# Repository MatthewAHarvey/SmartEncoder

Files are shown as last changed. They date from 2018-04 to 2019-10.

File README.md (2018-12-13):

# SmartEncoder
Arduino friendly, serially addressable, ATTINY85 based rotary encoders. Reduce the pin count from 3 * n where n is the number of encoders (pins A, B and button C) to 2 total. Serial in, Serial out. Use Hardware Serial, AltSoftSerial or Software Serial

Handling lots of encoders at the same time can be a challenge. For example, in our use case, we had 15 encoders attached to one Arduino Mega. After all the connections to other peripherals, we ran out of pins. The encoders had to be polled since there are not enough interrupts. Our solution is to offload the handling of the encoders to dedicated ATTINY85 chips. These then talk asynchronous serial at 125000 baud in a ring with the master arduino. The arduino now only needs 2 pins: 1 serial tx and 1 serial rx. At the moment this is limited to one of the hardware serial ports but tests show it's possible with software serial implementations.

In order for this to work, the ATTINY85s' clock frequencies must be set more accurately than straight from the factory. 

### Installation instructions:

1. First, the ATTINYs must be frequency calibrated. We do this by burning the arduino bootloader on to an ATTINY and uploading the FreqCal sketch. We use the [ATTINYCore](https://github.com/SpenceKonde/ATTinyCore) which must be installed in the Arduino IDE. We output a square wave from pin 6 and observe it using an oscilloscope. An attached rotary encoder is then used to adjust this signal until it is as close to 1 MHz as possible. Pressing the encoder button saves the current OSCCAL register value to the EEPROM. 

Arduino IDE settings for ATTINY85:
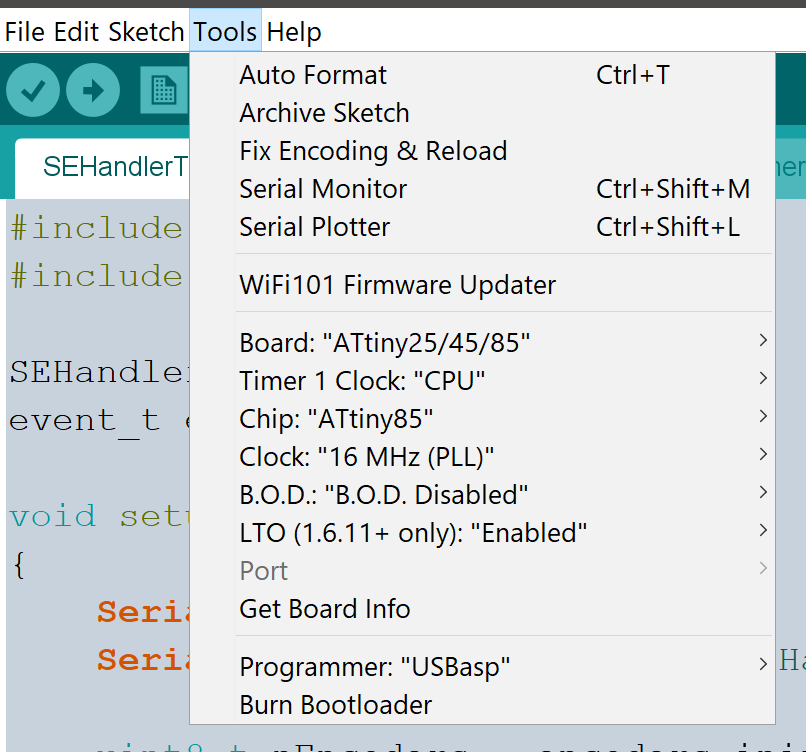
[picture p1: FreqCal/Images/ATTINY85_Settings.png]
ATTINY85 Settings


Schematic for the FreqCal rotary encoder programme:
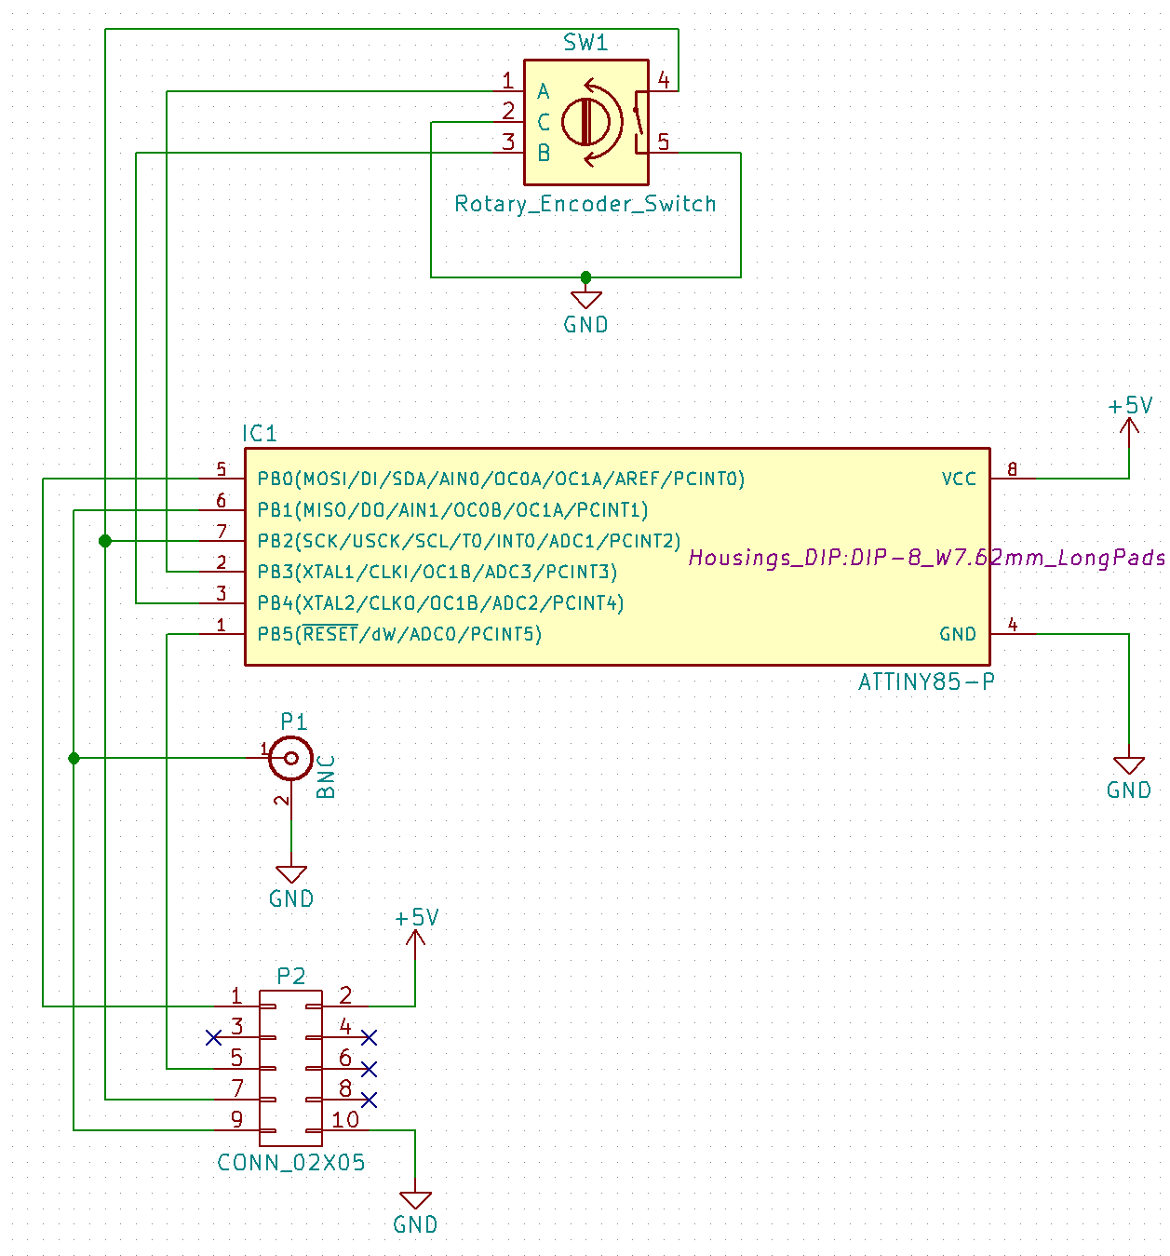
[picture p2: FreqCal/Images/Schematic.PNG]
Schematic


2. Now upload the ATTINY85RotEncCode sketch to each of the ATTINYs.

3. The example SEHandlerTest programme can be uploaded to the master arduino mega.

### To Do:
1. Add individual encoder direction swap command that can be called any time after init().
2. Add global encoder direction swap at creation time that tells all the individual encoders to swap direction at init time.

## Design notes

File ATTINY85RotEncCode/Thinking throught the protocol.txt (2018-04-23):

<C> is the command ascii letter
S for state (0 - off, 1 - encoder only, 2 - button only, 3 - both on)
D for debounce (0 to 9999ms)
C for double click max threshold (0 to 9999ms)
H for hold time min threshold (0 to 9999ms)
2 for encoder rate 2 max (0 to 9999ms)
3 for encoder rate 3 max (0 to 9999ms)

<STX><A1><A0><C><n3><n2><n1><n0><checksum><LF>

If I get <STX><0><2><H><1><0><0><0><checksum><LF> what happens?

<STX> starts serial message recording so msgIndex = 0
<0> goes in message[0], msgIndex = 1
<1> goes in message[1], msgIndex = 2
<H> goes in message[2], msgIndex = 3
<1> goes in message[3], msgIndex = 4
<0> goes in message[4], msgIndex = 5
<0> goes in message[5], msgIndex = 6
<0> goes in message[6], msgIndex = 7
<checksum> goes in message[7], msgIndex = 8
<LF> received so calculate checksum and parseMessage if it matches
    Checksum is message[msgIndex - 1]
    message to checksum is message[0] to message[6] 
    i.e. checksum(message, msgIndex)

What happens when I get a message?
1. If checksum matches
    2. If the message is set address, set my address, increment address, calculate new checksum and pass new message on
    3. Else If the message was global or for me, act on message and pass message along
    4. Else, pass message on
2. Else discard message

Build slave unit class on top of serial message class
Build master unit class on top of serial message class

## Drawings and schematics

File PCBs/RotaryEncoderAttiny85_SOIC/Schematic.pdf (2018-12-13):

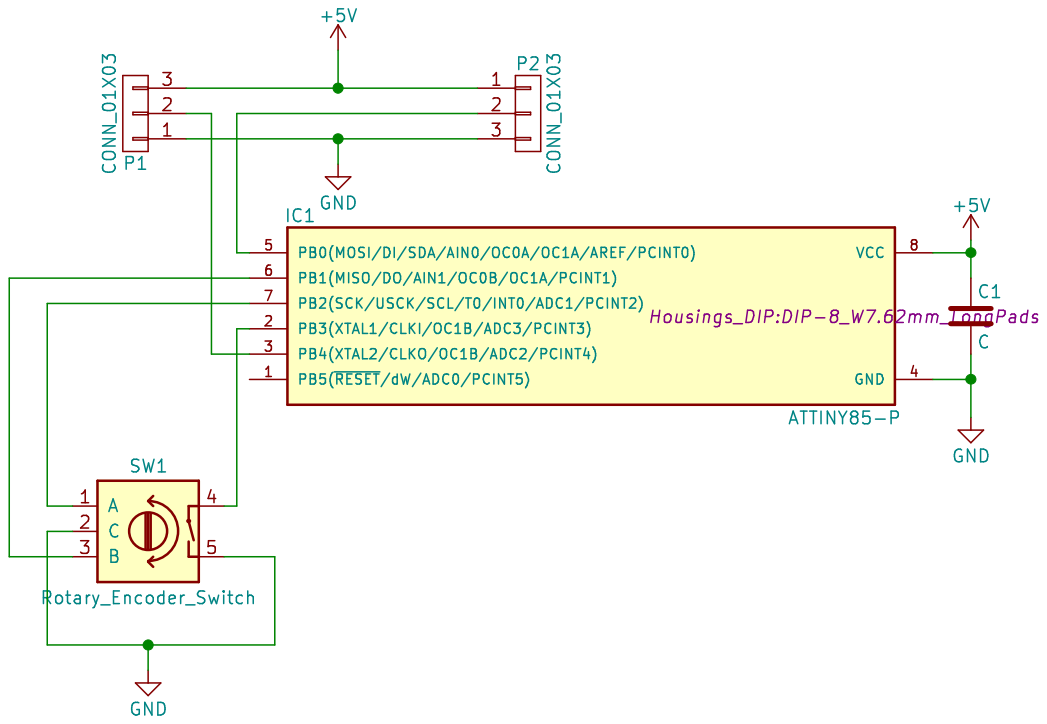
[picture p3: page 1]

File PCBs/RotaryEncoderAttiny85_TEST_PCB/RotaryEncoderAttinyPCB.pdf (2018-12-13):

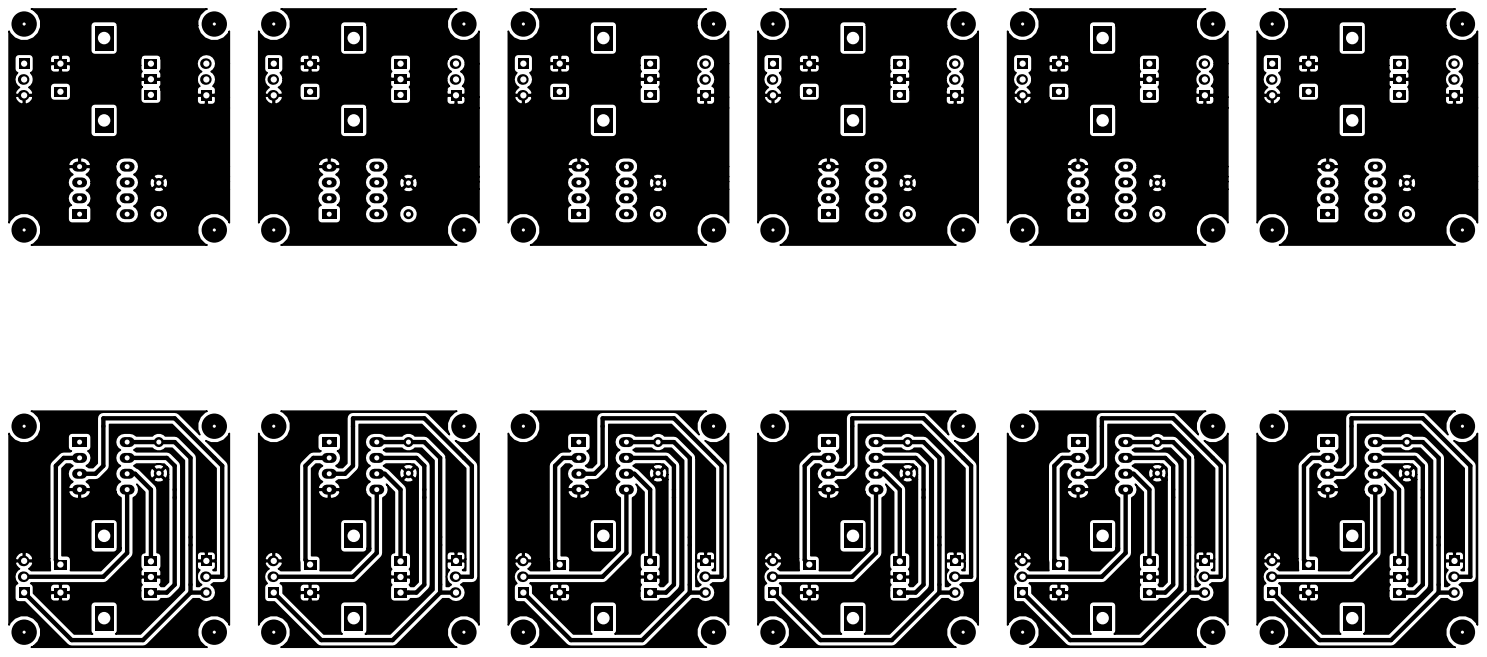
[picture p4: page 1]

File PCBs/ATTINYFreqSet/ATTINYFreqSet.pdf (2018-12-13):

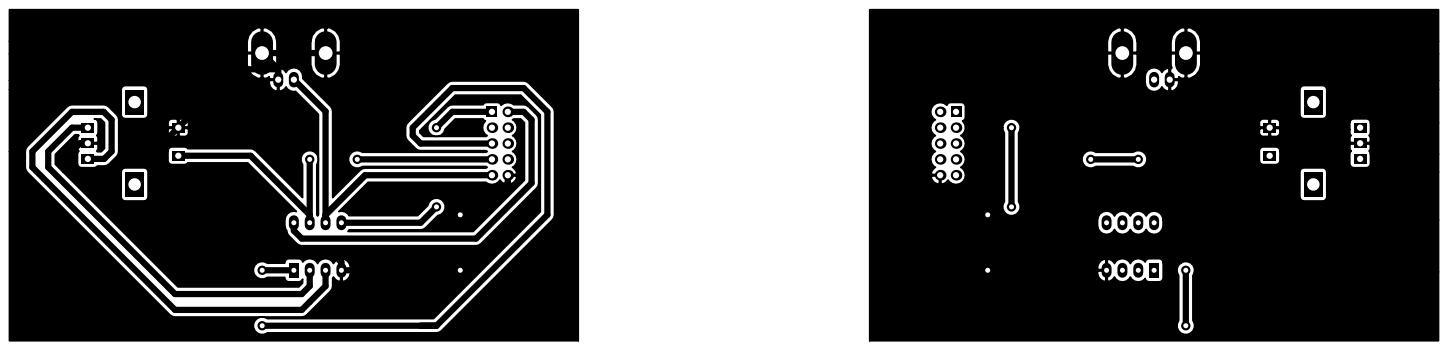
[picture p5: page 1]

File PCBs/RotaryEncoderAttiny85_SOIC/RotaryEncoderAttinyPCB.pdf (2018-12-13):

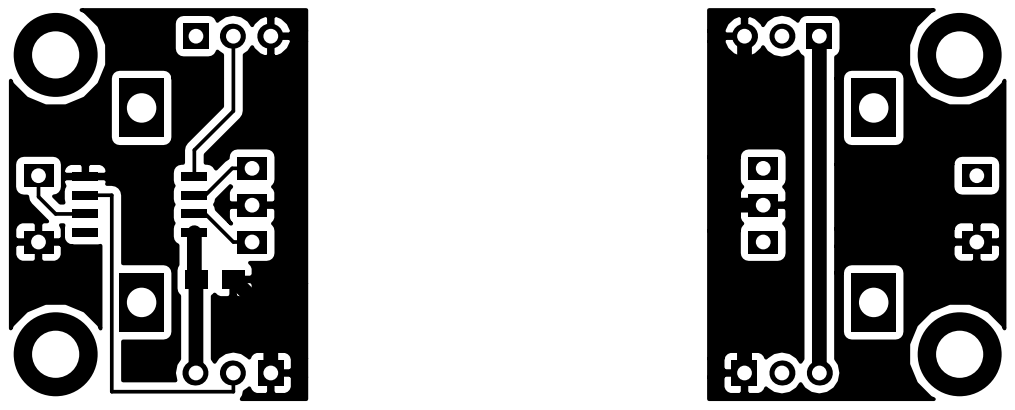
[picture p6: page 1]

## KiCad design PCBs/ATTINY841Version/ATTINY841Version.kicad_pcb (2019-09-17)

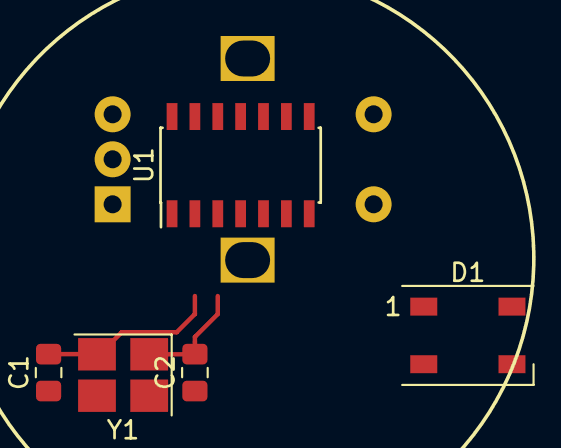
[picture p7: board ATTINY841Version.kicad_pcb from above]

Board: 2 copper layers, 6 parts (1 on the bottom side), 3 nets.

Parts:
C1, C2: C; C_0805_2012Metric_Pad1.15x1.40mm_HandSolder
D1: WS2812B; LED_WS2812B_PLCC4_5.0x5.0mm_P3.2mm
SW1: Rotary_Encoder_Switch; RotaryEncoder_Alps_EC12E-Switch_Vertical_H20mm
U1: ATtiny841-SSU; SOIC-14_3.9x8.7mm_P1.27mm
Y1: Crystal; Crystal_SMD_3225-4Pin_3.2x2.5mm_HandSoldering

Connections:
/XTAL1: C1.2, U1.2, Y1.2
/XTAL2: C2.2, U1.3, Y1.1
GND: C1.1, C2.1, SW1.C, SW1.S2, U1.14

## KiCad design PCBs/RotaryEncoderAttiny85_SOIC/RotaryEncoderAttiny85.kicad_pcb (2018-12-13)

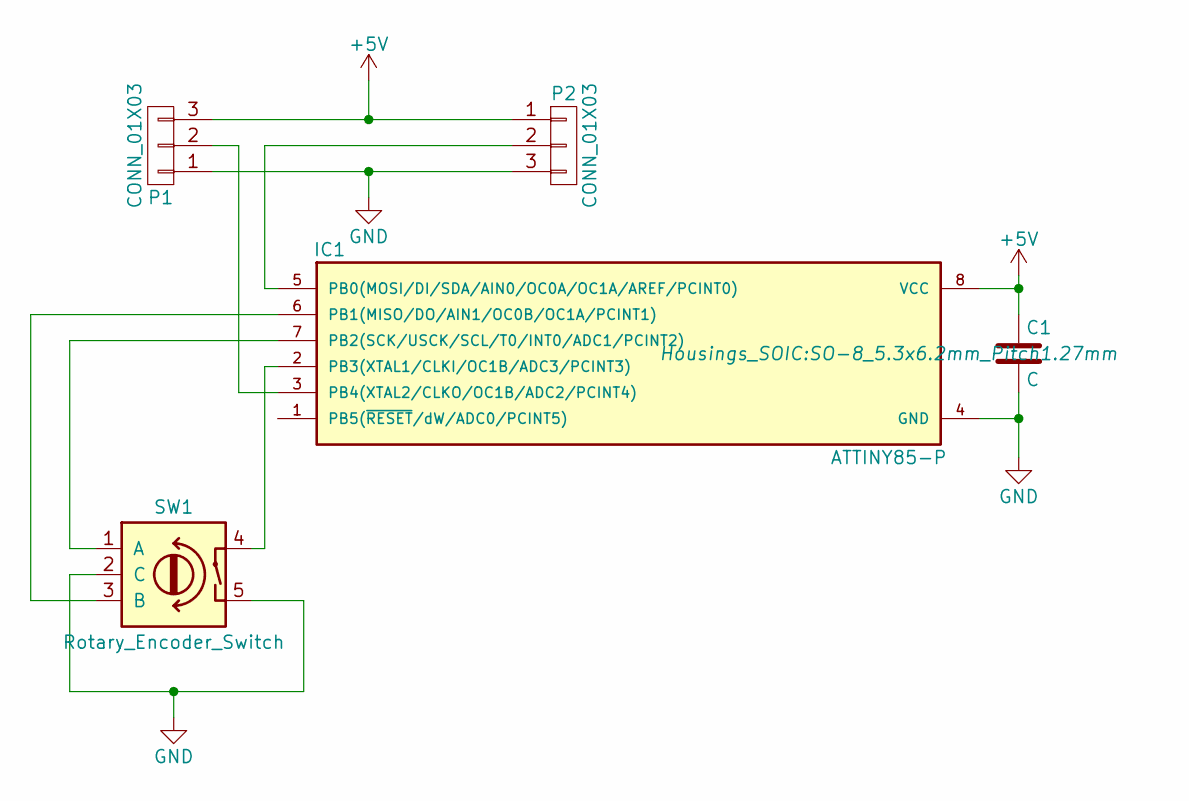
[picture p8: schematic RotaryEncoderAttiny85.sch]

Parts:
C1: C; C_0805_HandSoldering
IC1: ATTINY85-P; SO-8_5.3x6.2mm_Pitch1.27mm
P1, P2: CONN_01X03; Pin_Header_Straight_1x03_Pitch2.54mm
SW1: Rotary_Encoder_Switch; RotEnc

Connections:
+5V: C1.1, IC1.8 (VCC), P1.3, P2.1
GND: C1.2, IC1.4 (GND), P1.1, P2.3, SW1.2 (C), SW1.5
unnamed: IC1.2 (PB3(XTAL1/CLKI/OC1B/ADC3/PCINT3)), SW1.4
unnamed: IC1.3 (PB4(XTAL2/CLKO/OC1B/ADC2/PCINT4)), P1.2
unnamed: IC1.5 (PB0(MOSI/DI/SDA/AIN0/OC0A/OC1A/AREF/PCI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), P2.2
unnamed: IC1.6 (PB1(MISO/DO/AIN1/OC0B/OC1A/PCINT1)), SW1.3 (B)
unnamed: IC1.7 (PB2(SCK/USCK/SCL/T0/INT0/ADC1/PCINT2)), SW1.1 (A)

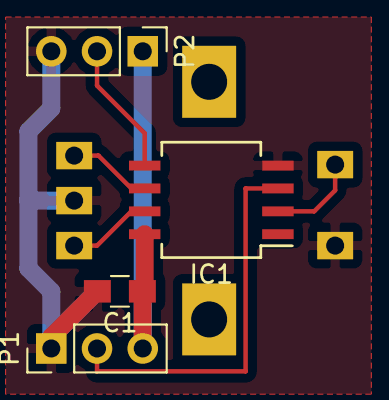
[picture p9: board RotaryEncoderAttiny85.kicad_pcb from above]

Board: 2 copper layers, 5 parts (1 on the bottom side), 7 nets.

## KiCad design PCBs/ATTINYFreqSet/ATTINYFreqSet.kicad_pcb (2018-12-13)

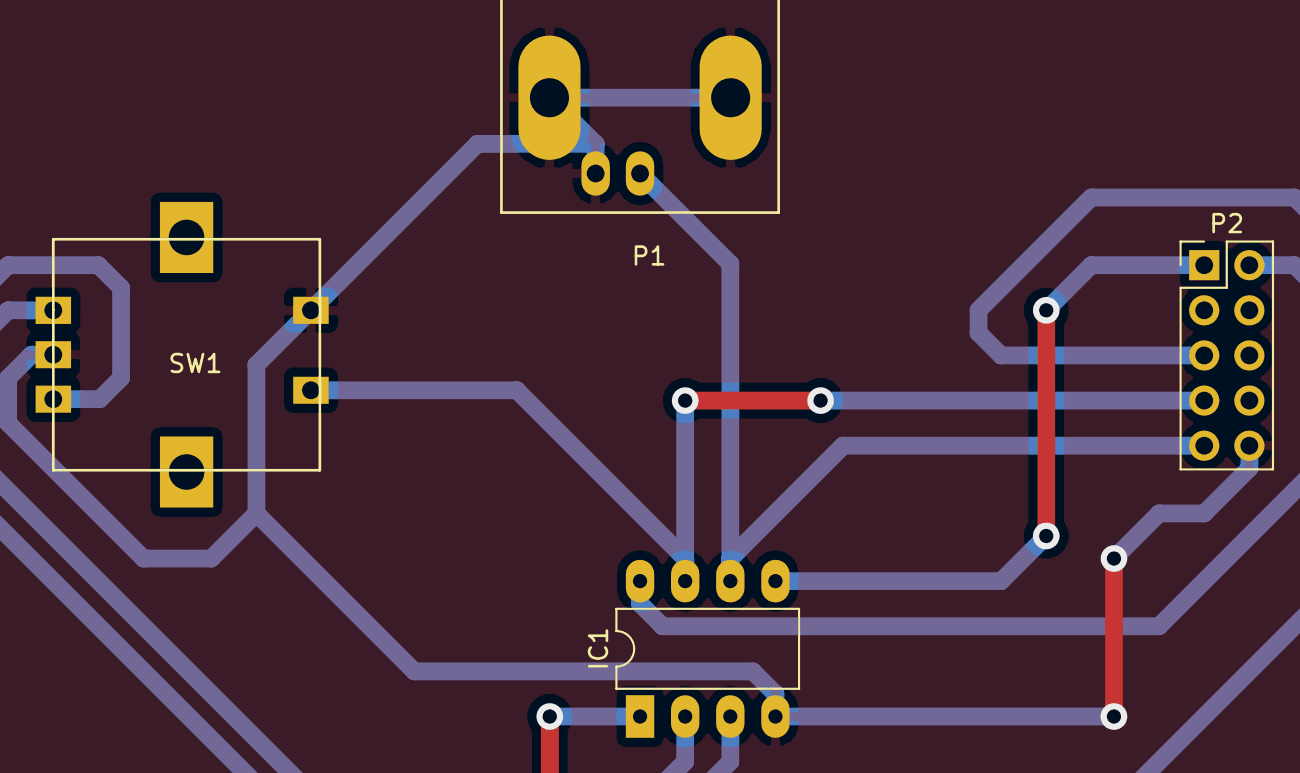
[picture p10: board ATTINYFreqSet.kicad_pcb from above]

Board: 2 copper layers, 4 parts (0 on the bottom side), 8 nets.

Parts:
IC1: ATTINY85-P; DIP-8_W7.62mm_LongPads
P1: BNC; BNC_Socket_TYCO-AMP_LargePads
P2: CONN_02X05; Pin_Header_Straight_2x05_Pitch2.54mm
SW1: Rotary_Encoder_Switch; RotEnc

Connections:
+5V: IC1.8, P2.2
GND: IC1.4, P1.2, P2.10, SW1.2, SW1.5
unnamed: IC1.1, P2.5
unnamed: IC1.2, SW1.1
unnamed: IC1.3, SW1.3
unnamed: IC1.5, P2.1
unnamed: IC1.6, P1.1, P2.9
unnamed: IC1.7, P2.7, SW1.4

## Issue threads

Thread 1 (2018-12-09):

SmartEncoder Pinout

rolfmeurer, 2018-12-09:
I'm a bit confused about diferent encoder pinout in  FreqCal.ino and ATTINY85RotEncCode.ino

is there a diferent hardware pinout for FreqCal and for the Main program?

I am up to design an encoder  PCB with LEDs, but it's not clear if the FreqCal schematic works as it is for the main program too.
Neither clear is the need of the Pushbutton wiring to the CONN_ß2X05  P2 connector. Is this only for the FreqCalc or for further usage too?

FreqCal.ino:
const int encPinA = 3; //pin 2
const int encPinB = 4; //pin 3
const int encPinC = 2; //pin 7

ATTINY85RotEncCode.ino:
const int encPinA = 2; //pin 7, PCINT2
const int encPinB = 1; //pin 6, PCINT1
const int encPinC = 3; //pin 2, PCINT3

MatthewAHarvey, 2018-12-10:
Hi Rolf,

I use the ATTINY85 without a crystal and the serial communications relies on all the ATTINY's clocks to be synchronised to within 1-2% or so. You can tune AVR chips by tweaking OSCCAL variable which I had done for previous projects. As such, I already had a board that I use to tune the frequencies. When the FreqCal.ino program is flashed to the ATTINY, I tune OSCCAL by watching a frequency generated
 on pin PB1. The rotary encoder changes the current OSCCAL and the encoder's button is pushed to set this value in the EEPROM. I read this value in all my subsequent ino scripts and set the frequency to that tuned OSCCAL in my void setup routine.

I made a little board that only has a BNC out to measure the frequency of a generated signal, a rotary encoder and a CONN_B2X05 connector which is used to plug in a USBASP programmer to flash the ATTINY chip with. Once I've set the OSCCAL freq, I reflash the chip with the smartencoder firmware and remove the chip from the board. I do this for all the chips in my project by first tuning the frequency on all the chips to be used, then flashing them all with the smartencoder firmware. Takes around a minute per chip. The programmer shares some pins with the rotary encoder on the board via the CONN_B2X05 connector. As long as I don't touch the encoder while the chip is being flashed, there are no problems doing this.

I have separate board layout for the smart encoder part that uses the pins set up in the ATTINY85RotEncCode.ino sketch. I should have uploaded this schematic and board layout too.

Does the above make sense?

I will remove the need for tuning the onboard oscillator frequency in future by using a chip with more pins available and hook up a crystal to provide a much more accurate clock.

Do you mind me asking what you have in mind with this code? I uploaded it here in this poorly documented state since I was explaining how to use it to colleagues and friends in person. I will tidy up the documentation and upload clearer code in the near future but probably not this week. If you would like a basic board layout for the smart encoder, I'll try to upload my Kicad projects here within a day or two.

Regards,
Matthew

rolfmeurer, 2018-12-11:
Hi Matthew,

Thank you for the kindly answer.

I have an encoder layout with an LED ring works perfectly, but needs an
arduino MINI PRO  each.

I hope I can merge your ATTiny smart encoder with my LED RING (using a
74HC595 4x4 LED matrix) to get it all on a tiny PCB  just as an universal
Encoder module.

It shouldn't become a little tiny module just 30x30mm as it is now and on
the buttom lay is still enough place to ge an ATTiny placed your FreqCalc
schematic fits onto the PCB

 Can you please send me a link to the schematic of the main smart encoder?

I'm fine with ATTINY a bigger chip would exceed the PCB layeout size

I'm working for KRAFTWERK and I'm always looking for new devices to give our
equipment more haptic.

Rregards,

Rolf

  _____

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

MatthewAHarvey, 2018-12-13:
Hi Rolf,

Your use case is exactly what I had in mind for this project so this is exciting. I am also interested in feedback and physical controls and have been disappointed with modern tactileless touchscreens appearing everywhere. Also, often modern controls just feel slow and clunky. The volume control knob in my car is very slow and the aircon temperature knob's encoder would miss events and not respond if not turned extremely slowly. That was very annoying in the summer heat when getting in to the car. I have thought about making a synthesizer but I have zero musical ability. KRAFTWERK is great too by the way.

I have just uploaded some Kicad projects to the PCBs subfolder for you. The ATTINYFreqSet board is my crude way to tune the oscillator frequencies and flash the chips before installing them in their final boards. The RotaryEncoderAttiny85_TEST_PCB one is my original test board where I daisy-chained 5 smart encoders together. Both of these boards use DIP packaged ATTINYs for ease of use while I developed the principle. The final board, RotaryEncoderAttiny85_SOIC, should work and on this one the ATTINY is a SOIC package and would fit beneath the encoder. I don't have a programmer board, or better still a header for programming the chip in place on this. The SOIC chips have been sat on my shelf for six months waiting for me...

At the moment, I used three for a LED strip controller toy that I built for my son and about 60 or so in a physics research lab where we build our own computer controlled power supplies etc. There are 3 power supplies with about 20 smart encoders each. This frees up a controlling arduino to respond to the power requirements and control requests whilst continuously updating an LCD panel at a much faster rate than an older design which had to poll many encoders. I can tell you that these power supplies have been in daily use for 6 months or so without a single problem so this serial daisy chain method seems to work very well. They don't look pretty because we didn't finish them before putting them in to use. One day...

Power supply control panels:
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

My son's toy during development (it's still not finished):
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

Very early test board and the one I used in my son's toy:
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

I have been discussing expanding on this smart encoder idea with some friends including status LEDs as you are doing. When a microcontroller is now so cheap, why not use many to make the design process easier and offload processing from the main controller?

The current firmware allows for the following events:
Clockwise rate 1
Clockwise rate 2
Clockwise rate 3
Anticlockwise rate 1
Anticlockwise rate 2
Anticlockwise rate 3
Button down
Button up
Button hold
Button doubleclick

The rates can be tuned to feel very good. For example, it's very easy to set our power supplies with milliVolt accuracy in 0.001V steps when rotating an encoder slowly, Move it in 0.1 Volt steps at a normal/natural rotation speed and very rapidly in say 10V steps for rapidly changing the voltage by a few hundred volts. It feels intuitive and makes our instruments very easy to tune. More than three rates could be used but I haven't coded them yet as we haven't felt the need. It would provide even more nuanced control though.

With regards to your LED ring, I don't think there are enough spare pins on an ATTINY85 to do this? As you can hopefully see from picture three though, there would be plenty of room to fit an MCU with more pins in SOIC package or possibly even DIP if it was mounted on the opposite side of the board and still fit your 74HC595 plus LEDs. For reference, the knobs on our power supplies are 36 mm apart and they are 40mm apart on my original test board. That board includes space for in and out connectors though so easily could be shrunk down.

I'll be updating the code to make it more readable soon. Especially the serial handling code on the ATTINY85RotEncCode.ino sketch.

Regards,
Matthew

rolfmeurer, 2018-12-13:
Hi Matthew,

Great project you Power Supply.

Nice and good readable Analyzer display design.

About the pins, the LED Ring is driven by a 74HC595.

So the Encoder and the LED ring could communicate serially  with the tiny

I think it  could work anyhow   by puzzle & pray

And one PCB should not exceed 30mm x 30mm to align them know by know
horizontally as well as vertically.

On my PCB top layer is still enough space to add a Tiny85 SOT and perhaps 4
resistors or capacitors .

Chips with more pin's I'm not sure it would match on the PCB, but if so,
then it's a great benefit.

Here comes a snap from a 9x9 encoder & LED proto PCB

Regards Rolf

  _____

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

MatthewAHarvey, 2018-12-13:
Hi Rolf,

Thanks for the comments about the analyser power supply, however I can not take credit for that design. My friend and colleague Ahmad designed and built those power supplies including all the display stuff. I just provided the smart encoder bit with a lot of input and help from Ahmad. He is visible in the background photo on his [website](https://ahmadsakaamini.com/about/), which was taken in our research lab.

Can you try attaching your picture again please? Nothing is showing. Perhaps I can help you with your design? Also, have you seen this [palettegear](https://palettegear.com/) stuff? Very slick and very expensive but they seem to have thought along the same/similar lines to us.

Matthew

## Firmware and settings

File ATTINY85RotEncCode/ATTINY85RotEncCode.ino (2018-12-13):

// ATTINY85 code for rotary encoder
// 16 MHz PLL works well.
// Enable BOD to prevent frozen states of the ATTINY in the case of a power dip.
// Must flash FreqCal and adjust oscillator with oscilloscope or frequency counter to ensure serial works properly
// Tested with 3 encoders and a hardware serial port on a mega, each message takes 5us and I can generate over 400 events per second when turning an encoder as fast as I can. It goes even faster when I turn two encoders. There will be misses but this is still a responsive system.

#include "Encoder.h"
#include <SoftwareSerial.h>
#include <EEPROM.h>

const long baudrate = 125000;
const int tx = 0; // software serial transmit. pin 5
const int rx = 4; // software serial receive. pin 3
SoftwareSerial SSerial(rx, tx);

// define pins. A=2,B=1 for Ahmad's power supplies
const int encPinA = 2; //pin 6, PCINT1
const int encPinB = 1; //pin 7, PCINT2
const int encPinC = 3; //pin 2, PCINT3
bool reverseDirection = false; // By default, keep direction as wired in reference design
Encoder enc(encPinA, encPinB, encPinC);

// start and stop chars
const char STX = 0x02; // start transmission ascii code
const char LF = 0x0A; // line feed ascii code

uint8_t msgIndex;
static const uint8_t LEN = 9;
char message[LEN]; // max length of a message. NOT terminated by \0   

//int address = -1;
char address[] = "00";
uint8_t addressInt = 0;

//typedef enum {WAITING_FOR_ADDRESS, RUNNING} runModes;
//typedef enum {WAITING_FOR_START, COLLECTING_MESSAGE} serialModes;
enum runModes{WAITING_FOR_ADDRESS, RUNNING};
enum serialModes{WAITING_FOR_START, COLLECTING_MESSAGE};

runModes state;
serialModes serialState;

// Protocol:
// No rotary encoder events will be registered until the unit has received an address.
// The address takes the form of two hex chars to allow the address of a unit to be set between 0 and 254. All units respond to 255 since this is the global update address.
// The master must send <STX><Address1><Address0><checksum><LF> to set the first unit's address. This unit then increments this address and passes it on. Do not overflow 254!!!
// Set the debounce with <STX><A1><A0><D><n><checksum><LF> where n is the debounce time in milliseconds.
// Enable or disable the encoder with <STX><A1><A0><E><n><checksum><LF> where n is 1 or 0.

// Except for address messages, all messages are echoed.
// Rotary encoder events are broadcast <STX><A1><A0><x><checksum><LF> where A1, A0 give the encoder address 
// and x is 0 for clockwise step at rate 1
//          1 for clockwise step at rate 2
//          2 for clockwise step at rate 3
//          3 for anti-clockwise step at rate 1
//          4 for anti-clockwise step at rate 2
//          5 for anti-clockwise step at rate 3
//          6 for button up
//          7 for button down
//          8 for button doubleclick
//          9 for button hold


void setup()
{
    updateOscFreq();

    enc.init();
    SSerial.begin(baudrate);
    //state = RUNNING;
    state = WAITING_FOR_ADDRESS;
    serialState = WAITING_FOR_START;    
}

void loop()
{
    checkSerial();
    checkEncoder();
}

void checkEncoder()
{
    if(state == RUNNING)
    {
        if(!reverseDirection)
        {
            switch(enc.poll())
            {
                case NO_CHANGE:
                    break;
                case CW_RATE1: 
                    sendState(0);
                    break;
                case CW_RATE2:
                    sendState(1);
                    break;
                case CW_RATE3: 
                    sendState(2);
                    break;
                case ACW_RATE1: 
                    sendState(3);
                    break;
                case ACW_RATE2: 
                    sendState(4);
                    break;
                case ACW_RATE3: 
                    sendState(5);
                    break;
                case BUTTON_UP: 
                    sendState(6);
                    break;
                case BUTTON_DOWN: 
                    sendState(7);
                    break;
                case BUTTON_DOUBLECLICK: 
                    sendState(8);
                    break;
                case BUTTON_HOLD:
                    sendState(9);
                    break;
            }
        }
        else
        {
            switch(enc.poll())
            {
                case NO_CHANGE:
                    break;
                case CW_RATE1: 
                    sendState(3);
                    break;
                case CW_RATE2:
                    sendState(4);
                    break;
                case CW_RATE3: 
                    sendState(5);
                    break;
                case ACW_RATE1: 
                    sendState(0);
                    break;
                case ACW_RATE2: 
                    sendState(1);
                    break;
                case ACW_RATE3: 
                    sendState(2);
                    break;
                case BUTTON_UP: 
                    sendState(6);
                    break;
                case BUTTON_DOWN: 
                    sendState(7);
                    break;
                case BUTTON_DOUBLECLICK: 
                    sendState(8);
                    break;
                case BUTTON_HOLD:
                    sendState(9);
                    break;
            }
        }
    }
}

void updateOscFreq()
{
    if(EEPROM.read(0) == 'C' && EEPROM.read(1) == 'A' && EEPROM.read(2) == 'L')
    {
        OSCCAL = EEPROM.read(3);
    }
}

void sendState(int i)
{
    if(0 <= i && i < 10)
    {
        message[0] = address[0];
        message[1] = address[1];
        message[2] = i + '0';
        message[3] = calcChecksum(message, 3);

        SSerial.write(STX);
        for(int i = 0; i < 4; i++)
        {
            SSerial.write(message[i]);
        }
        SSerial.write(LF);
    }
}

void checkSerial()
{
    while(SSerial.available())
    {
        char in = SSerial.read();
        
        switch(serialState)
        {
            case WAITING_FOR_START:
                if(in == STX)
                {
                    serialState = COLLECTING_MESSAGE;
                    msgIndex = 0;
                }
                break;
            case COLLECTING_MESSAGE:
                if(in == LF)
                {
                    serialState = WAITING_FOR_START;
                    // Calculate checksum and make sure it matches. If it does, parse the message
                    uint8_t msgLen = msgIndex - 1;
                    if(message[msgLen] == calcChecksum(message, msgLen))
                    {
                        // Parse message
                        //SSerial.write(STX);
                        //SSerial.print("Received good message.");
                        //SSerial.write(LF);
                        parseMessage();
                    }
                }
                else if(in == STX)
                {
                    //something must have glitched so reset msgIndex to start again
                    msgIndex = 0;
                }
                else if(msgIndex < LEN)
                {
                    message[msgIndex] = in;
                    msgIndex++;
                }
                else
                {
                    //message would now be too long so go back to waiting for a new reading
                    serialState = WAITING_FOR_START;
                }
                break;
        }
    }
}

void parseMessage()
{
    char type = message[2];
    unsigned int value = 0;
    switch(msgIndex)
    {
        case 3: // set address and set mode to RUNNING
            if(validAddress())
            {
                address[0] = message[0];
                address[1] = message[1];
                state = RUNNING;
                // Now we need to increment the address and pass it on. To do this, convert the address to an int, increment it, convert it back to hex array then send this.
                sendNextSetAddress();
            }
            break;
        case 4: // get value of something
            //char type = message[2];
            if(addressMatch())
            {
                message[0] = address[0]; // update these in case the message was to all units.
                message[1] = address[1];
                switch(type)
                {
                    case '2': // rate 2 max (ms)
                        value = enc.getRate2Max();
                        break;
                    case '3': // rate 3 max (ms)
                        value = enc.getRate3Max();
                        break;
                    case 'C': // double click max (ms)
                        value = enc.getDoubleClickMax();
                        break;
                    case 'D': // button debounce time (ms)
                        value = enc.getDebounceTime();
                        break;
                    case 'H': // hold button min (ms)
                        value = enc.getButtonHoldTime();
                        break;
                    case 'R':
                        value = (uint16_t) reverseDirection;
                        break;
                    case 'S': // set the state of the encoder
                        // 0 button and encoder disabled
                        // 1 button enabled, encoder disabled
                        // 2 button diasbled, encoder enabled
                        // 3 both enabled
                        value = enc.getState();
                        break;
                }
                sendValue(value);
            }
            else
            {
                echoSerial();
            }
            break;
        case 5: // If the length is between 5 and 8, a value is being set between 0 and 9999 (usually ms).
        case 6:
        case 7:
        case 8:
            // Echo the message so that it reaches the master. This way the master can check setting messages were received, and any encoder updates get passed along.
            echoSerial();
            // Now check whether I need to set something
            if(addressMatch() || globalMatch())
            {
                // The message is for us so parse it
                //char type = message[2];
                int value = messageToInt(3);
                switch(type)
                {
                    case '2': // rate 2 max (ms)
                        enc.setRate2Max(value);
                        break;
                    case '3': // rate 3 max (ms)
                        enc.setRate3Max(value);
                        break;
                    case 'C': // double click max (ms)
                        enc.setDoubleClickMax(value);
                        break;
                    case 'D': // button debounce time (ms)
                        enc.setDebounceTime(value);
                        break;
                    case 'H': // hold button min (ms)
                        enc.setButtonHoldTime(value);
                        break;
                    case 'R':
                        reverseDirection = (bool) value;
                        break;
                    case 'S': // set the state of the encoder
                        // 0 button and encoder disabled
                        // 1 button enabled, encoder disabled
                        // 2 button diasbled, encoder enabled
                        // 3 both enabled
                        enc.setState(value);
                        break;
                }
            }
            break;
    }
}

void sendValue(unsigned int value)
{
    message[0] = address[0];
    message[1] = address[1];
    uint8_t msgLen = 3 + nDigits(value);
    for(int i = 0; i < msgLen - 3; i++)
    {
        message[msgLen - 1 - i] = (value % 10) + '0';
        value /= 10;
    }

    SSerial.write(STX);
    for(int i = 0; i < msgLen; i++)
    {
        SSerial.write(message[i]);
    }
    SSerial.write(calcChecksum(message, msgLen));
    SSerial.write(LF);
}

void sendNextSetAddress()
{
    // Works out what number address this unit has, increments it and sends that on as two hexidecimal digits to the next unit.
    uint8_t addressInt = 16 * hexTo_uint8_t(address[0]) + hexTo_uint8_t(address[1]);
    message[0] = uint8_tToHex((addressInt + 1) / 16);
    message[1] = uint8_tToHex((addressInt + 1) % 16);
    message[2] = calcChecksum(message, 2);
    
    SSerial.write(STX);
    for(int i = 0; i < 3; i++)
    {
        SSerial.write(message[i]);
    }
    SSerial.write(LF);
}

bool addressMatch()
{
    if(message[0] == address[0] && message[1] == address[1]) { return true; }
    else                                                     { return false; }
}

bool globalMatch()
{
    if(message[0] == 'F' && message[1] == 'F') { return true; }
    else                                       { return false; }
}

bool validAddress()
{
    // both A1 and A0 must be a hex numeral
    for(int i = 0; i < 2; i++)
    {
        if(message[i] < '0' || message[i] > 'F' || ('9' < message[i] && message[i] < 'A')) 
        {
            return false;
        }
        return true;
    }
}

char uint8_tToHex(uint8_t n)
{
    if(n < 10) { return n + 48; }
    else       { return n + 55; }
}

int messageToInt(int startIndex)
{
    // Returns the number stored in a char array, starting at startIndex
    int number = 0;
    for(int i = startIndex; i < msgIndex - 1; i++) // msgIndex - 1 because we don't include the checksum!
    {
        number *= 10;
        number += (message[i] -'0');
    }
    return number;
}

uint8_t hexTo_uint8_t(char c)
{
    // If c - 48 is less than 10, return it. Otherwise, subtract a bit more because c must have been A to F.
    c -= '0';
    if(c < 10) { return c; }
    else       { return c - 7;}
}

uint8_t nDigits(unsigned int i)
{
    if(i > 9999)    { return 5;}
    else if(i > 999){ return 4;}
    else if(i > 99) { return 3;}
    else if(i > 9)  { return 2;}
    else            { return 1;}
}

void echoSerial()
{
    // Send the message buffer on
    SSerial.write(STX);
    //SSerial.print("Echo: ");
    for(int i = 0; i < msgIndex; i++)
    {
        SSerial.write(message[i]);
    }
    SSerial.write(LF);
}

char calcChecksum(char* rawMessage, int len)
{
    unsigned int checksum=0;
    for(int i = 0; i < len; i++)
    { //add the command
        checksum += rawMessage[i];
    }
    //Calculate checksum based on MPS manual
    checksum = ~checksum+1; //the checksum is currently a unsigned 16bit int. Invert all the bits and add 1.
    checksum = 0x7F & checksum; // discard the 8 MSBs and clear the remaining MSB (B0000000001111111)
    checksum = 0x40 | checksum; //bitwise or bit6 with 0x40 (or with a seventh bit which is set to 1.) (B0000000001000000)
    return (char) checksum;
}

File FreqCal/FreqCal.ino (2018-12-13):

//Program to calibrate the internal oscillator of an ATTINY85
//Once the fuses have been set to use the PLL at 16MHz, run this program and watch output on scope/frequency counter.
//Use Timer1 in CTC
//According to oscilloscope, this is spot on 1MHz. Should mean software serial works.

//Added a rotary encoder. Watch the frequency on the scope and change it with the encoder. Press button to write to EEPROM.

#include <EEPROM.h>
#include "Encoder.h"

// define pins
const int encPinA = 4; //pin 2 
const int encPinB = 3; //pin 3 
const int encPinC = 2; //pin 7

Encoder enc(encPinA, encPinB, encPinC);


void setup() {
    // put your setup code here, to run once:
    DDRB |= (1 << DDB1); // set PB1 to output mode
    PORTB |= (1 << PORTB1); //set output of PB1 to 1 initially.
    TCNT1 = 0; //Initialise the Timer1 counter value to 0

    // TCCR1 is the Timer/Counter1 Control Register
    TCCR1 = 0; // set everything to 0 which is the default anyway.
    TCCR1 |= (1 << CTC1); // Set the bit7 to 1 so that the timer is reset on a match with OCR1C
    TCCR1 |= (1 << COM1A0); // if COM1A1 is zero and COM1A0 is one, the output will toggle when TCNT1 == OCR1C
    TCCR1 |= (1 << CS10); // set prescaler to 1. Without this, the counter is disabled.

    //OCR1C = 0; // when this is zero, the output frequency should be f = 16M/(2*P*(1+OCR1C) = 8MHz where P is the prescaler factor
    OCR1C = 7; // when this is 7, the output frequency should be f = 16M/(2*P*(1+OCR1C) = 1MHz where P is the prescaler factor

    // Check for an existing calibration set in the EEPROM and if so, start from there.
    if(EEPROM.read(0) == 'C' && EEPROM.read(1) == 'A' && EEPROM.read(2) == 'L')
    {
        OSCCAL = EEPROM.read(3);
    }

    

    enc.init();
}

void loop() {
    // put your main code here, to run repeatedly:
    switch(enc.poll())
    {
        case NO_CHANGE:
            break;
        case CW_RATE1: 
              
        case CW_RATE2:
            
        case CW_RATE3: 
            OSCCAL++;
            break;
        case ACW_RATE1: 
            
        case ACW_RATE2: 
            
        case ACW_RATE3: 
            OSCCAL--;
            break;
        case BUTTON_UP: 
            EEPROM.update(0, 'C'); // Write CAL so the main code can check for this pattern. If it isn't present, it will not update OSCCAL.
            EEPROM.update(1, 'A');
            EEPROM.update(2, 'L');
            EEPROM.update(3, OSCCAL);
            break;
        case BUTTON_DOWN: 
            break;
        case BUTTON_DOUBLECLICK: 
            break;
        case BUTTON_HOLD:
            break;
    }
}

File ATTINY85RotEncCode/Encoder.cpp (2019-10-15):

#include "Encoder.h"
#include "arduino.h"
#include "MilliTimer.h"

Encoder::Encoder(){

}

Encoder::Encoder(uint8_t pinA, uint8_t pinB)
{
    _pinA = pinA;
    _pinB = pinB;
    buttonEnabled = false;
}

Encoder::Encoder(uint8_t pinA, uint8_t pinB, uint8_t pinC)
{
    _pinA = pinA;
    _pinB = pinB;
    _pinC = pinC;
}

void Encoder::init()
{
    pinMode(_pinA, INPUT_PULLUP);
    pinMode(_pinB, INPUT_PULLUP);
    if(buttonEnabled) { pinMode(_pinC, INPUT_PULLUP); }

    buttonDebounceTimer.updateTimeOut(buttonDebounceTime);
    buttonHoldTimer.updateTimeOut(buttonHoldMin);
    buttonDoubleClickTimer.updateTimeOut(doubleClickMax);
}

void Encoder::init(uint8_t pinA, uint8_t pinB){
    _pinA = pinA;
    _pinB = pinB;
    buttonEnabled = false;

    pinMode(_pinA, INPUT_PULLUP);
    pinMode(_pinB, INPUT_PULLUP);

    // buttonDebounceTimer.updateTimeOut(buttonDebounceTime);
    // buttonHoldTimer.updateTimeOut(buttonHoldMin);
    // buttonDoubleClickTimer.updateTimeOut(doubleClickMax);
}

void Encoder::init(uint8_t pinA, uint8_t pinB, uint8_t pinC){
    _pinA = pinA;
    _pinB = pinB;
    _pinC = pinC;
    pinMode(_pinA, INPUT_PULLUP);
    pinMode(_pinB, INPUT_PULLUP);
    pinMode(_pinC, INPUT_PULLUP);

    buttonDebounceTimer.updateTimeOut(buttonDebounceTime);
    buttonHoldTimer.updateTimeOut(buttonHoldMin);
    buttonDoubleClickTimer.updateTimeOut(doubleClickMax);
}

resultEnum Encoder::poll(bool rateless)
{
    
    if(buttonEnabled)
    {
        Cold = C;
        C = digitalRead(_pinC);
        if(C != Cold && buttonDebounceTimer.timedOut(true))
        {
            // Button state has changed
            if(C) //Button has been pressed
            {
                if(!buttonDoubleClickTimer.timedOut(true))
                {
                    return BUTTON_DOUBLECLICK;
                }
                else
                {
                    buttonDoubleClickTimer.reset();
                    return BUTTON_UP;
                }
            }
            else // Button has been pressed or released
            {
                buttonHoldTimer.reset();
                return BUTTON_DOWN;
            }
        }
        else if(!C) // button is being held down
        {
            if(buttonHoldTimer.timedOut(true))
            {
                return BUTTON_HOLD;
            }
        }
    }

    if(encoderEnabled)
    {
        Aold = A;
        Bold = B;
        A = digitalRead(_pinA);
        B = digitalRead(_pinB);
        if(A != Aold || B != Bold)
        {
            // Something has changed so evaluate
            DEBUG_PRINT(A);
            DEBUG_PRINT(B);
            DEBUG_PRINT(": ");
            switch(state)
            {
                case IDLE:
                    //DEBUG_PRINTLN("IDLE");
                    if(!A && B)
                    {
                        // Start of anticlockwise turn
                        DEBUG_PRINTLN("IDLE to ACW1");
                        state = ACW1;
                    }
                    else if(A && !B)
                    {
                        // Start of clockwise turn
                        DEBUG_PRINTLN("IDLE to CW1");
                        state = CW1;
                    }
                    else
                    {
                        // Reading not valid so ignore
                        DEBUG_PRINTLN("Invalid so IDLE to IDLE");
                        state = IDLE;
                    }
                    break;
                case ACW1:
                    //DEBUG_PRINTLN("ACW1");
                    if(!A && !B)
                    {
                        // Valid move so increment state
                        DEBUG_PRINTLN("ACW1 to ACW2");
                        state = ACW2;
                    }
                    else if(A && B)
                    {
                        // Bounced back to idle
                        DEBUG_PRINTLN("ACW1 to IDLE");
                        state = IDLE;
                    }
                    else
                    {
                        // Illegal reading so will have to reset
                        DEBUG_PRINTLN("Invalid so ACW1 to IDLE");
                        state = IDLE;
                    }
                    break;
                case ACW2:
                    //DEBUG_PRINTLN("ACW2");
                    if(A && !B)
                    {
                        // Valid move so increment state
                        DEBUG_PRINTLN("ACW2 to ACW3");
                        state = ACW3;
                    }
                    else if(!A && B)
                    {
                        // bounced backwards
                        DEBUG_PRINTLN("ACW2 to ACW1");
                        state = ACW1;
                    }
                    else
                    {
                        // Illegal reading so will have to reset
                        DEBUG_PRINTLN("Invalid so ACW2 to IDLE");
                        state = IDLE;
                    }
                    break;
                case ACW3:
                    //DEBUG_PRINTLN("ACW3");
                    if(A && B)
                    {
                        // One whole step completed!
                        DEBUG_PRINTLN("Valid Step, Increment to IDLE");
                        state = IDLE;
                        unsigned int encoderTimeDiff = encoderTimer.elapsed();
                        encoderTimer.reset();
                        if(encoderTimeDiff < rate3Threshold && !rateless)
                        {
                            return ACW_RATE3;
                        }
                        else if(encoderTimeDiff < rate2Threshold && !rateless)
                        {
                            return ACW_RATE2;
                        }
                        else
                        {
                            return ACW_RATE1;
                        }
                    }
                    else if(!A && !B)
                    {
                        // Bounced backwards so decrement
                        DEBUG_PRINTLN("ACW3 to ACW2");
                        state = ACW2;
                    }
                    else
                    {
                        // Invalid so reset
                        DEBUG_PRINTLN("Invalid so ACW3 to IDLE");
                        state = IDLE;
                    }
                    break;
                case CW1:
                    //DEBUG_PRINTLN("CW1");
                    if(!A && !B)
                    {
                        // Valid move so increment state
                        DEBUG_PRINTLN("CW1 to CW2");
                        state = CW2;
                    }
                    else if(A && B)
                    {
                        // Bounced back to idle
                        DEBUG_PRINTLN("CW1 to IDLE");
                        state = IDLE;
                    }
                    else
                    {
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

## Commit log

2018-04-25 Updated readme and added a schematic
2018-04-28 Added Rateless option to poll()
    Sometimes you don't want to have to check for turn rate1, 2 or 3 and only want to know which way the encoder was rotated. poll(true) or poll_rateless return all clockwise events as CW_RATE1 and antic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
2018-04-28 Rateless options added to Encoder class as well
2018-12-13 Some fixes and added PCBs
    I haven't looked at this in a while but here are some PCBs and a few bug fixes to the code. The code is about to get an overhaul to make it more readable but is working as is.
    The PCBs are in use except for the SOIC version which I haven't tested yet.
    [ATTINYFreqSet-2018-06-21-16-11-18.sch, ATTINYFreqSet.kicad_pcb, ATTINYFreqSet.sch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]
2019-09-17 attiny841 work in progress
    Work in progress for different chip
    [ATTINY841Version.kicad_pcb, ATTINY841Version.sch, _saved_ATTINY841Version.sch]
